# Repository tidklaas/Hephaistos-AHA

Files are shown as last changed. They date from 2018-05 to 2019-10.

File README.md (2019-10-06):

# Hephaistos-AHA
Control your heater from your FritzBox, if you dare...

This project emulates a room thermostat for a central heating unit.
It monitors a set of AVM FritzDect 301 (intelligent radiator valves)
and signals the heater to turn on or off via a simple relay circuit.

Since we are dealing with mains voltage and probably gas-powered
heating systems, you should not even think about using this contraption
unless your are a licensed electrician and/or certified HVAC technician.

Seriously, don't.

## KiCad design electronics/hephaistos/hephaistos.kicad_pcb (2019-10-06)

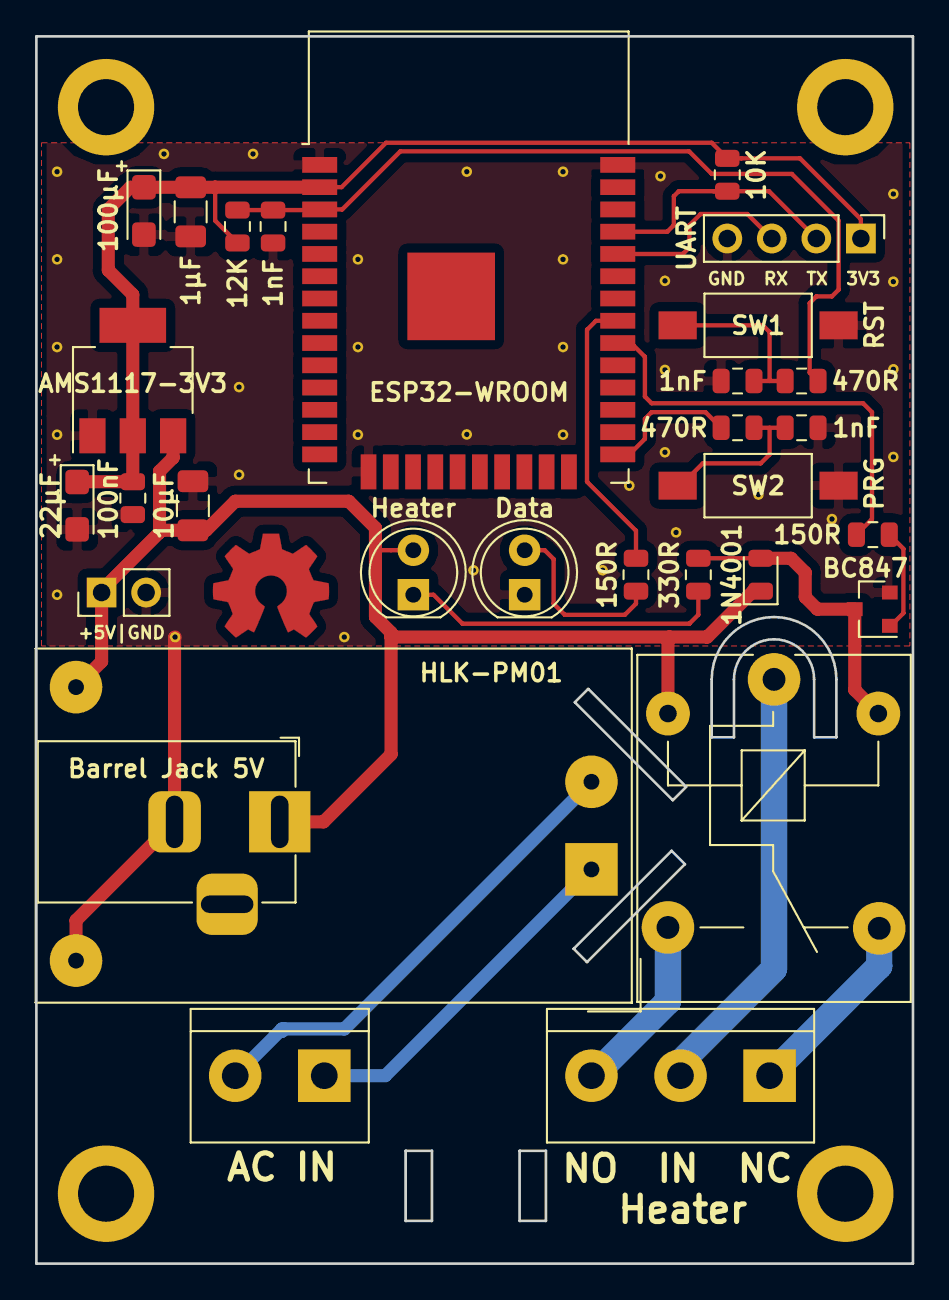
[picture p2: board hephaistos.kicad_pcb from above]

Board: 2 copper layers, 50.0 x 70.0 mm, 30 parts (0 on the bottom side), 20 nets.

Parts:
C1: 100µF; CP_EIA-3216-12_Kemet-S
C2: 1µF; C_1206_3216Metric
C3, C4, C5: 1nF; C_0805_2012Metric
C6: 10µF; C_1206_3216Metric
C7: 22µF; CP_EIA-3216-12_Kemet-S
C8: 100nF; C_0805_2012Metric
D1: Heater; LED_D5.0mm
D2: Data; LED_D5.0mm
D3: 1N4001; D_0805_2012Metric
J1: UART; PinHeader_1x04_P2.54mm_Vertical
J2: Heater; TerminalBlock_bornier-3_P5.08mm
J3: AC IN; TerminalBlock_bornier-2_P5.08mm
J4: Barrel Jack 5V; BarrelJack_Horizontal
J5: +5V Pin Header; PinHeader_1x02_P2.54mm_Vertical
K1: SANYOU_SRD_Form_C; Relay_SPDT_SANYOU_SRD_Series_Form_C
Q1: BC847; SOT-23
R1: 12K; R_0805_2012Metric
R2, R3: 470R; R_0805_2012Metric
R4: 330R; R_0805_2012Metric
R5, R7: 150R; R_0805_2012Metric
R6: 10K; R_0805_2012Metric
SW1: EN; SW_SPST_FSMSM
SW2: BOOT; SW_SPST_FSMSM
U1: ESP32-WROOM; ESP32-WROOM-32
U2: AMS1117-3V3; SOT-223-3_TabPin2
U3: HLK-PM01; Converter_ACDC_Hi-Link_HLK-PMXX_THT

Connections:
+3V3: C1.1, C2.1, C7.1, C8.1, J1.1, R1.1, R6.2, U1.2, U2.2
+5V: C6.1, D1.2, D3.1, J4.1, J5.1, K1.2, U2.3, U3.4
/IO0: R3.1, U1.25
/IO18: R5.2, U1.30
/IO19: R7.2, U1.31
/REL_IN: J2.2, K1.1
/REL_NC: J2.1, K1.4
/REL_NO: J2.3, K1.3
/RX0: J1.3, U1.34
/TX0: J1.2, R6.1, U1.35
GND: C1.2, C2.2, C3.2, C4.2, C5.2, C6.2, C7.2, C8.2, D2.1, J1.4, J4.2, J5.2, Q1.2, SW1.1, SW2.1, U1.1, U1.15, U1.38, U2.1, U3.3
unnamed: C3.1, R1.2, R2.1, U1.3
unnamed: C4.1, R2.2, SW1.2
unnamed: C5.1, R3.2, SW2.2
unnamed: D1.1, R4.2
unnamed: D2.2, R7.1
unnamed: D3.2, K1.5, Q1.3, R4.1
unnamed: J3.1, U3.1
unnamed: J3.2, U3.2
unnamed: Q1.1, R5.1

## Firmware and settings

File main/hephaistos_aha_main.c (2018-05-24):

/*
 * main.c
 *
 *  Created on: 04.11.2017
 *      Author: tido
 */

#include <string.h>
#include <stdlib.h>
#include <unistd.h>
#include <stdbool.h>
#include <sys/socket.h>
#include <netdb.h>
#include <netinet/in.h>
#include <arpa/inet.h>
#include <errno.h>
#include <expat.h>
#include <expat-dom.h>
#include <list.h>
#if !defined(ESP_PLATFORM)
#include <bsd/bsd.h>
#endif

#include <sdkconfig.h>

#if defined(ESP_PLATFORM)
#include "freertos/FreeRTOS.h"
#include "freertos/task.h"
#include "freertos/event_groups.h"
#include "esp_wifi.h"
#include "esp_event_loop.h"
#include "esp_log.h"
#include "esp_system.h"
#include "esp_task_wdt.h"
#include "nvs_flash.h"
#include "driver/gpio.h"

#include "lwip/err.h"
#include "lwip/sockets.h"
#include "lwip/sys.h"
#include "lwip/netdb.h"
#include "lwip/dns.h"

#include "apps/sntp/sntp.h"
#endif // defined(ESP_PLATFORM)

#include "mbedtls/platform.h"
#include "mbedtls/net_sockets.h"
#if defined(ESP_PLATFORM)
#include "mbedtls/esp_debug.h"
#endif // defined(ESP_PLATFORM)
#include "mbedtls/ssl.h"
#include "mbedtls/entropy.h"
#include "mbedtls/ctr_drbg.h"
#include "mbedtls/error.h"
#include "mbedtls/certs.h"
#include "mbedtls/md5.h"

/* The examples use simple WiFi configuration that you can set via
 'make menuconfig'.

 If you'd rather not, just change the below entries to strings with
 the config you want - ie #define EXAMPLE_WIFI_SSID "mywifissid"
 */
#define WIFI_SSID       CONFIG_WIFI_SSID
#define WIFI_PASS       CONFIG_WIFI_PASSWORD
#define FBOX_USER       CONFIG_FBOX_USER
#define FBOX_PASS       CONFIG_FBOX_PASSWORD
#define FBOX_ADDR       CONFIG_FBOX_ADDR
#define FBOX_PORT       CONFIG_FBOX_PORT
#define TIMEZONE        CONFIG_TIMEZONE
#define GPIO_HEAT       CONFIG_GPIO_HEAT
#define GPIO_LED        CONFIG_GPIO_LED

#define TWDT_TIMEOUT_S          300
#define TASK_RESET_PERIOD_S     5

#if defined(ESP_PLATFORM)
/* FreeRTOS event group to signal when we are connected & ready to make a request */
static EventGroupHandle_t wifi_event_group;

/* The event group allows multiple bits for each event,
 * but we only care about one event - are we connected
 * to the AP with an IP? */
const int CONNECTED_BIT = BIT0;
#else
#define ESP_LOGE(tag, format, ... )  printf("[%s]" format "\n", tag, ##__VA_ARGS__)
#define ESP_LOGI(tag, format, ... )  printf("[%s]" format "\n", tag, ##__VA_ARGS__)
#define ESP_LOGW(tag, format, ... )  printf("[%s]" format "\n", tag, ##__VA_ARGS__)
#define ESP_LOGD(tag, format, ... )  printf("[%s]" format "\n", tag, ##__VA_ARGS__)
#endif // defined(ESP_PLATFORM)

#define ARRAY_SIZE(x)   (sizeof(x) / sizeof(*(x)))
static void debug_led(unsigned int led, int on_off);

static const char *TAG = "hephaistos";

static const char *HTTP_REQ = 
        "GET %s HTTP/1.0\r\n"
        "HOST: 192.168.178.1\r\n"
        "CONNECTION: keep-alive\r\n"
        "USER-AGENT: AVM UPnP/1.0 Client 1.0\r\n"
        "\r\n";

static const char *SID_CHECK = "/login_sid.lua?sid=%s";
static const char *SID_GET = "/login_sid.lua?username=%s&response=%s-%s";
static const char *HKR_REQ = "/webservices/homeautoswitch.lua?switchcmd=getdevicelistinfos&sid=%s";

#define HTTP_REQ_SIZE   1024

enum aha_heat_mode {
    aha_heat_off = 0,
    aha_heat_keep,
    aha_heat_on
};

struct aha_state
{
#if defined(ESP_PLATFORM)
    SemaphoreHandle_t sema;
    TimerHandle_t hyst_timer;
#endif
    struct aha_list_head dev_head; // list of all devices
    struct aha_list_head grp_head; // list of all groups
};

static struct aha_state state;

#define MAX_ENTRY_LEN       128
#define MAX_GROUP_MEMBERS   16

#define HEAT_FORCE_ON   0xFE
#define HEAT_FORCE_OFF  0xFD

enum aha_entry_type
{
    aha_type_invalid = 0,
    aha_type_device,
    aha_type_group,
};

enum aha_lock_mode
{
    aha_lock_unknown = 0,
    aha_lock_on,
    aha_lock_off,
};

enum aha_switch_mode
{
    aha_switch_unknown = 0,
    aha_switch_auto,
    aha_switch_manual,
};

enum aha_switch_state
{
    aha_swstate_unknown = 0,
    aha_swstate_on,
    aha_swstate_off,
};

enum aha_alarm_mode
{
    aha_alarm_unknown = 0,
    aha_alarm_off,
    aha_alarm_on,
};

struct aha_hkr
{
    bool present;
    unsigned long set_temp;
    unsigned long act_temp;
    unsigned long comfort_temp;
    unsigned long eco_temp;
    unsigned long next_temp;
    unsigned long next_change;
    unsigned long batt_low;
    enum aha_lock_mode lock;
    enum aha_lock_mode device_lock;
    unsigned long error;
};

struct aha_switch
{
    bool present;
    enum aha_switch_state state;
    enum aha_switch_mode mode;
    enum aha_lock_mode lock;
    enum aha_lock_mode device_lock;
};

struct aha_power
{
    bool present;
    unsigned long power;
    unsigned long energy;
};

struct aha_thermo
{
    bool present;
    long temp_c;
    long offset;
};

struct aha_alarm
{
    bool present;
    enum aha_alarm_mode mode;
};

struct aha_group
{
    bool present;
    unsigned long master_dev;
    unsigned long members[MAX_GROUP_MEMBERS];
    unsigned int member_cnt;
};

struct aha_device
{
    struct aha_list_head dev_list;
    struct aha_list_head grp_list;
    struct aha_list_head member_list;
    enum aha_entry_type type;
    char name[MAX_ENTRY_LEN];
    char identifier[MAX_ENTRY_LEN];
    char fw_version[MAX_ENTRY_LEN];
    char manufacturer[MAX_ENTRY_LEN];
    char product_name[MAX_ENTRY_LEN];
    unsigned long functions;
    unsigned long id;
    unsigned long present;
    struct aha_device *group;
    struct aha_group grp;
    struct aha_switch swi;
    struct aha_power pwr;
    struct aha_thermo temp;
    struct aha_alarm alarm;
    struct aha_hkr hkr;
};

static int initialise_state(void)
{
    int result;

    result = 0;
    memset(&state, 0x0, sizeof(state));

    AHA_INIT_LIST_HEAD(&state.dev_head);
    AHA_INIT_LIST_HEAD(&state.grp_head);

#if defined(ESP_PLATFORM)
    state.sema = xSemaphoreCreateBinary();
    if(state.sema == NULL){
        ESP_LOGE(TAG, "Creating semaphore failed");
        result = -ENOMEM;
    }
#endif

    return result;
}

#if defined(ESP_PLATFORM)
static esp_err_t event_handler(void *ctx, system_event_t *event)
{
    switch(event->event_id) {
    case SYSTEM_EVENT_STA_START:
        esp_wifi_connect();
        break;
    case SYSTEM_EVENT_STA_GOT_IP:
        xEventGroupSetBits(wifi_event_group, CONNECTED_BIT);
        break;
    case SYSTEM_EVENT_STA_DISCONNECTED:
        /* This is a workaround as ESP32 WiFi libs don't currently
         * auto-reassociate. */
        esp_wifi_connect();
        xEventGroupClearBits(wifi_event_group, CONNECTED_BIT);
        break;
    default:
        break;
    }
    return ESP_OK;
}

static void initialise_wifi(void)
{
    tcpip_adapter_init();
    wifi_event_group = xEventGroupCreate();

    ESP_ERROR_CHECK(esp_event_loop_init(event_handler, NULL));

    wifi_init_config_t cfg = WIFI_INIT_CONFIG_DEFAULT();

    ESP_ERROR_CHECK(esp_wifi_init(&cfg));
    ESP_ERROR_CHECK(esp_wifi_set_storage(WIFI_STORAGE_RAM));

    wifi_config_t wifi_config = {
        .sta = {
            .ssid = WIFI_SSID,
            .password =  WIFI_PASS,
        },
    };

    ESP_LOGI(TAG, "Setting WiFi configuration SSID %s...", wifi_config.sta.ssid);

    ESP_ERROR_CHECK(esp_wifi_set_mode(WIFI_MODE_STA));
    ESP_ERROR_CHECK(esp_wifi_set_config(ESP_IF_WIFI_STA, &wifi_config));
    ESP_ERROR_CHECK(esp_wifi_start());
}
#endif // defined(ESP_PLATFORM)

struct auth_data
{
    char user[128];
    char pass[128];
    char realm[128];
    char nonce[128];
    char auth[128];
    char sid[128];
};

int gen_tr064_auth(struct auth_data *data)
{
    mbedtls_md5_context ctx;
    unsigned char md5sum[16];
    unsigned char md5str[33];
    unsigned int i;

    memset(data->auth, 0x0, sizeof(data->auth));

    mbedtls_md5_init(&ctx);
    mbedtls_md5_starts(&ctx);
    mbedtls_md5_update(&ctx, (unsigned char *) data->user, strlen(data->user));
    mbedtls_md5_update(&ctx, (unsigned char *) ":", 1);
    mbedtls_md5_update(&ctx, (unsigned char *) data->realm, strlen(data->realm));
    mbedtls_md5_update(&ctx, (unsigned char *) ":", 1);
    mbedtls_md5_update(&ctx, (unsigned char *) data->pass, strlen(data->pass));
    mbedtls_md5_finish(&ctx, md5sum);
    mbedtls_md5_free(&ctx);

    for(i = 0; i < sizeof(md5sum); ++i){
        sprintf((char *) &(md5str[2 * i]), "%02x", md5sum[i]);
    }

    mbedtls_md5_init(&ctx);
    mbedtls_md5_starts(&ctx);
    mbedtls_md5_update(&ctx, md5str, 32);
    mbedtls_md5_update(&ctx, (unsigned char *) ":", 1);
    mbedtls_md5_update(&ctx, (unsigned char *) data->nonce,
            strlen(data->nonce));
    mbedtls_md5_finish(&ctx, md5sum);
    mbedtls_md5_free(&ctx);

    memset(data->auth, 0x0, sizeof(data->auth));
    for(i = 0; i < sizeof(md5sum); ++i){
        sprintf(&(data->auth[2 * i]), "%02x", md5sum[i]);
    }

    return 0;
}

int gen_sid_auth(struct auth_data *data)
{
    mbedtls_md5_context ctx;
    unsigned char md5sum[16];
    unsigned char buf[256];
    unsigned int i, curr;

    memset(data->auth, 0x0, sizeof(data->auth));

    curr = 0;
    memset(buf, 0x0, sizeof(buf));
    for(i = 0;i < strlen(data->nonce);++i){
        buf[curr] = data->nonce[i];
        curr += 2;
    }

    buf[curr] = '-';
    curr += 2;

    for(i = 0; i < strlen(data->pass); ++i){
        buf[curr] = data->pass[i];
        curr += 2;
    }

    mbedtls_md5_init(&ctx);
    mbedtls_md5_starts(&ctx);
    mbedtls_md5_update(&ctx, (unsigned char *) buf, curr);
    mbedtls_md5_finish(&ctx, md5sum);
    mbedtls_md5_free(&ctx);

    memset(data->auth, 0x0, sizeof(data->auth));
    for(i = 0; i < sizeof(md5sum); ++i){
        sprintf(&(data->auth[2 * i]), "%02x", md5sum[i]);
    }

    return 0;
}

static int do_http_req(char *host, char *service, dom_t **dom, const char *req)
{
    char buf[64];
    char *reply;
    size_t written, len;
    void *dom_parser;
    int body, result, sock;
    struct addrinfo hints;
    struct addrinfo *info;
    struct timeval receiving_timeout;

    sock = -1;
    info = NULL;
    memset(&hints, 0x0, sizeof(hints));
    hints.ai_family = AF_INET;
    hints.ai_socktype = SOCK_STREAM;

    result = getaddrinfo(host, service, &hints, &info);

    if(result != 0 || info == NULL){
        ESP_LOGE(TAG, "DNS lookup failed err=%d %s info=%p", result, strerror(errno), info);
        goto err_out;
    }

    sock = socket(info->ai_family, info->ai_socktype, 0);
    if(sock < 0){
        ESP_LOGE(TAG, "... Failed to allocate socket.");
        result = sock;
        goto err_out;
    }

    result = connect(sock, info->ai_addr, info->ai_addrlen);
    if(result != 0){
        ESP_LOGE(TAG, "... socket connect failed result=%d", result);
        goto err_out;
    }

    written = 0;
    len = strlen(req);

    while(len > 0){
        result = write(sock, &(req[written]), len);
        if(result < 0){
            ESP_LOGE(TAG, "... socket send failed");
            goto err_out;
        }
        written += result;
        len -= result;
    }

    receiving_timeout.tv_sec = 5;
    receiving_timeout.tv_usec = 0;
    result = setsockopt(sock, SOL_SOCKET, SO_RCVTIMEO, &receiving_timeout,
            sizeof(receiving_timeout));
    if(result < 0){
        ESP_LOGE(TAG, "... failed to set socket receiving timeout");
        goto err_out;
    }

    body = 0;
    memset(buf, 0x42, 3);
    dom_parser = NULL;

    do{
        len = sizeof(buf) - 4;
        bzero(&(buf[3]), sizeof(buf) - 3);
        result = read(sock, (unsigned char *) &(buf[3]), len);
        if(result < 0){
            ESP_LOGE(TAG, "... failed to set socket receiving timeout");
            goto err_out;
        }

        /* connection closed? */
        if(result == 0){
            break;
        }

        len = result;

        if(body == 0){
            reply = strstr(buf, "\r\n\r\n");
            if(reply == NULL){
                memmove(buf, &(buf[len]), 3);
                continue;
            }
            reply += strlen("\r\n\r\n");
            len -= (reply - &(buf[3]));
            body = 1;
        }else{
            reply = &buf[3];
        }

        result = dom_parse_chunked_data(&dom_parser, dom, reply, len, 0);
    }while(1);

    result = dom_parse_chunked_data(&dom_parser, dom, NULL, 0, 1);

err_out:
    if(info != NULL){
        freeaddrinfo(info);
    }

    if(sock >= 0){
        close(sock);
    }

    if(result != 0 && *dom != NULL){
        dom_free(*dom);
        *dom = NULL;
    }

    return result;
}

static int parse_attr_ul(dom_t *dom, const char *name, unsigned long *dst)
{
    int result;
    const char *val;

    result = 0;
    val = dom_find_attr(dom->attr, name);
    if(val == NULL){
        result = -ENOENT;
        goto err_out;
    }

    errno = 0;
    *dst = strtoul(val, NULL, 10);
    result = errno;

err_out:
    return result;
}

static int __attribute__((unused)) parse_attr_long(dom_t *dom, const char *name, long *dst)
{
    int result;
    const char *val;

    result = 0;
    val = dom_find_attr(dom->attr, name);
    if(val == NULL){
        result = -ENOENT;
        goto err_out;
    }

    errno = 0;
    *dst = strtol(val, NULL, 10);
    result = errno;

err_out:
    return result;
}

static int parse_data_ul(dom_t *dom, const char *name, unsigned long *dst)
{
    int result;
    dom_t *node;
    char buf[32];

    result = 0;
    node = dom_find_node(dom, name);
    if(node == NULL){
        result = -ENOENT;
        goto err_out;
    }

    if(node->data_len >= (sizeof(buf) - 1)){
        result = -EINVAL;
        goto err_out;
    }

    memcpy(buf, node->data, node->data_len);
    buf[node->data_len] = '\0';

    errno = 0;
    *dst = strtoul(buf, NULL, 10);
    result = errno;

err_out:
    return result;
}

static int parse_data_long(dom_t *dom, const char *name, long *dst)
{
    int result;
    dom_t *node;
    char buf[32];

    result = 0;
    node = dom_find_node(dom, name);
    if(node == NULL){
        result = -ENOENT;
        goto err_out;
    }

    if(node->data_len >= (sizeof(buf) - 1)){
        result = -ENOSPC;
        goto err_out;
    }

    memcpy(buf, node->data, node->data_len);
    buf[node->data_len] = '\0';

    errno = 0;
    *dst = strtol(buf, NULL, 10);
    result = errno;

err_out:
    return result;
}

static int copy_attr_str(dom_t *dom, const char *name, char *dst, size_t len)
{
    const char *attr;
    size_t written;
    int result;

    result = 0;
    attr = dom_find_attr(dom->attr, name);
    if(attr == NULL){
        result = -ENOENT;
        goto err_out;
    }

    written = strlcpy(dst, attr, len);
    if(written >= len){
        result = -ENOSPC;
    }

err_out:
    return result;
}

static int copy_data_str(dom_t *dom, const char *name, char *dst, size_t len)
{
    dom_t *node;
    int result;

    result = 0;
    node = dom_find_node(dom, name);
    if(node == NULL){
        result = -ENOENT;
        goto err_out;
    }

    if(node->data_len >= len){
        result = -ENOSPC;
        goto err_out;
    }

    memcpy(dst, node->data, node->data_len);
    dst[node->data_len] = '\0';

err_out:
    return result;
}

static int parse_lock_state(dom_t *dom, const char *name, enum aha_lock_mode *state)
{
    unsigned long tmp;
    int result;

    result = parse_data_ul(dom, name, &tmp);
    if(result == 0){
        switch(tmp){
        case 0:
            *state = aha_lock_off;
            break;
        case 1:
            *state = aha_lock_on;
            break;
        default:
            result = -EINVAL;
            goto err_out;
        }
    }

err_out:
    return result;
}

static int parse_switch_state(dom_t *dom, const char *name, enum aha_switch_state *state)
{
    unsigned long tmp;
    int result;

    result = parse_data_ul(dom, name, &tmp);
    if(result == 0){
        switch(tmp){
        case 0:
            *state = aha_swstate_off;
            break;
        case 1:
            *state = aha_swstate_on;
            break;
        default:
            result = -EINVAL;
            goto err_out;
        }
    }

err_out:
    return result;
}

static int compare_data_str(dom_t *dom, const char *name, const char *val)
{
    dom_t *node;
    int result;

    result = 0;
    node = dom_find_node(dom, name);
    if(node == NULL){
        result = -ENOENT;
        goto err_out;
    }

    if(strncasecmp(val, node->data, node->data_len) != 0){
        result = 1;
    }

err_out:
    return result;
}

static int parse_switch_mode(dom_t *dom, const char *name, enum aha_switch_mode *mode)
{
    int result;

    result = compare_data_str(dom, name, "auto");
    if(result < 0){
        result = -EINVAL;
        goto err_out;
    } else if(result == 0){
        *mode = aha_switch_auto;
        goto err_out;
    }

    result = compare_data_str(dom, name, "manuell");
    if(result < 0){
        result = -EINVAL;
        goto err_out;
    } else if(result == 0){
        *mode = aha_switch_manual;
        goto err_out;
    }

    result = -ENOENT;

err_out:
    return result;
}

static int parse_group_entry(dom_t *dom, struct aha_device *entry)
{
    dom_t *node;
    char buf[MAX_ENTRY_LEN];
    char *tok, *saveptr;
    unsigned long val;
    int result;

    result = 0;
    node = dom_find_node(dom, "groupinfo");
    if(node == NULL){
        goto err_out;
    }

    node = node->child;

    result = parse_data_ul(node, "masterdeviceid", &(entry->grp.master_dev));
    if(result != 0 && result != -ENOENT){
        ESP_LOGE(TAG, "Parsing masterdeviceid failed for entry %s", entry->name);
        goto err_out;
    }
    result = 0;

    result = copy_data_str(node, "members", buf, sizeof(buf));
    if(result != 0){
        ESP_LOGE(TAG, "Copying member string failed for entry %s", entry->name);
        result = -EINVAL;
        goto err_out;
    }

    tok = strtok_r(buf, ",", &saveptr);
    while(tok != NULL && entry->grp.member_cnt < ARRAY_SIZE(entry->grp.members)){
        errno = 0;
        val = strtoul(tok, NULL, 10);
        if(errno != 0){
            ESP_LOGE(TAG, "Error parsing group members for entry %s", entry->name);
            result = errno;
            goto err_out;
        }

        entry->grp.members[entry->grp.member_cnt] = val;
        ++entry->grp.member_cnt;
        tok = strtok_r(NULL, ",", &saveptr);
    }

    entry->grp.present = true;

err_out:
    return result;
}

static int parse_hkr_entry(dom_t *dom, struct aha_device *entry)
{
    dom_t *node;
    int result;

    result = 0;
    node = dom_find_node(dom, "hkr");
    if(node == NULL){
        goto err_out;
    }

    node = node->child;

    result = parse_data_ul(node, "tist", &(entry->hkr.act_temp));
    if(result != 0){
        ESP_LOGE(TAG, "Error parsing actual temperature for entry %s", entry->name);
        goto err_out;
    }

    result = parse_data_ul(node, "tsoll", &(entry->hkr.set_temp));
    if(result != 0){
        ESP_LOGE(TAG, "Error parsing set temperature for entry %s", entry->name);
        goto err_out;
    }

    result = parse_data_ul(node, "komfort", &(entry->hkr.comfort_temp));
    if(result != 0){
        ESP_LOGE(TAG, "Error parsing comfort temperature for entry %s", entry->name);
        goto err_out;
    }

    result = parse_data_ul(node, "absenk", &(entry->hkr.eco_temp));
    if(result != 0){
        ESP_LOGE(TAG, "Error parsing eco temperature for entry %s", entry->name);
        goto err_out;
    }

    result = parse_data_ul(node, "errorcode", &(entry->hkr.error));
    if(result != 0){
        ESP_LOGE(TAG, "Error parsing error code for entry %s", entry->name);
        goto err_out;
    }

    result = parse_data_ul(node, "batterylow", &(entry->hkr.batt_low));
    if(result != 0){
        ESP_LOGE(TAG, "Error parsing battery status for entry %s", entry->name);
        goto err_out;
    }

    result = parse_data_ul(node, "endperiod", &(entry->hkr.next_change));
    if(result != 0){
        ESP_LOGE(TAG, "Error parsing next change time for entry %s", entry->name);
        goto err_out;
    }

    result = parse_data_ul(node, "tchange", &(entry->hkr.next_temp));
    if(result != 0){
        ESP_LOGE(TAG, "Error parsing next change temperature for entry %s", entry->name);
        goto err_out;
    }

    result = parse_lock_state(node, "lock", &(entry->hkr.lock));
    if(result != 0){
        ESP_LOGE(TAG, "Error parsing hkr lock state for entry %s", entry->name);
        goto err_out;
    }

    result = parse_lock_state(node, "devicelock", &(entry->hkr.device_lock));
    if(result != 0){
        ESP_LOGE(TAG, "Error parsing hkr device lock state for entry %s", entry->name);
        goto err_out;
    }

    entry->hkr.present = true;

err_out:
    return result;
}

static int parse_swi_entry(dom_t *dom, struct aha_device *entry)
{
    dom_t *node;
    int result;

    result = 0;
    node = dom_find_node(dom, "switch");
    if(node == NULL){
        goto err_out;
    }

    node = node->child;

    result = parse_switch_state(dom, "state", &(entry->swi.state));
    if(result != 0){
        ESP_LOGE(TAG, "Error parsing switch state for entry %s", entry->name);
        goto err_out;

    }

    result = parse_switch_mode(dom, "mode", &(entry->swi.mode));
    if(result != 0){
        ESP_LOGE(TAG, "Error parsing switch state for entry %s", entry->name);
        goto err_out;

    }

    result = parse_lock_state(node, "lock", &(entry->swi.lock));
    if(result != 0){
        ESP_LOGE(TAG, "Error parsing switch lock state for entry %s", entry->name);
        goto err_out;
    }

    result = parse_lock_state(node, "devicelock", &(entry->swi.device_lock));
    if(result != 0){
        ESP_LOGE(TAG, "Error parsing switch device lock state for entry %s", entry->name);
        goto err_out;
    }

    entry->swi.present = true;

err_out:
    return result;
}
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
int main(int argc, char **argv)
{
    get_time();
    initialise_state();
    hephaistos_task(NULL);
    return 0;
}
#endif

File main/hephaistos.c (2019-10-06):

/*
 * This file is part of the Hephaistos-AHA project.
 * Copyright (C) 2018-2019 Tido Klaassen <tido_hephaistos@4gh.eu>
 *
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
 * You should have received a copy of the GNU General Public License
 * along with this program; if not, write to the Free Software
 * Foundation, Inc., 51 Franklin Street, Fifth Floor, Boston,
 * MA  02110-1301, USA.
 */

#include <string.h>
#include <stdlib.h>
#include <unistd.h>
#include <stdbool.h>
#include <sys/socket.h>
#include <netdb.h>
#include <netinet/in.h>
#include <arpa/inet.h>
#include <errno.h>

#include <sdkconfig.h>

#include <hephaistos.h>
#include <avm_aha.h>

#include <freertos/FreeRTOS.h>
#include <freertos/task.h>
#include <freertos/event_groups.h>
#include <esp_wifi.h>
#include <esp_wps.h>
#include <esp_event.h>
#include <esp_log.h>
#include <esp_system.h>
#include <esp_task_wdt.h>
#include <nvs_flash.h>
#include <driver/gpio.h>
#include <driver/ledc.h>
#include <esp_intr_alloc.h>
#include <esp32/rom/rtc.h>
#include <esp_ota_ops.h>
#include <esp_image_format.h>
#include <esp_sntp.h>

#include <lwip/err.h>
#include <lwip/sockets.h>
#include <lwip/sys.h>
#include <lwip/netdb.h>
#include <lwip/dns.h>

#include <wifi_manager.h>
#include <libesphttpd/cgiwifi.h>
#include <http_srv.h>

#define TIMEZONE        CONFIG_TIMEZONE
#define GPIO_HEAT       CONFIG_GPIO_HEAT
#define GPIO_LED        CONFIG_GPIO_LED
#define GPIO_FW_RESET   CONFIG_GPIO_FW_RESET

#define TWDT_TIMEOUT_S          300
#define TASK_RESET_PERIOD_S     5
#define FW_RESET_TIME           10

static struct heph_cfg heph_cfg;
static char sntp_srv[64];

static SemaphoreHandle_t cfg_lock = NULL;

static EventGroupHandle_t heph_event_group;
static TimerHandle_t heph_timer = NULL;
static TimerHandle_t fwrst_timer = NULL;

#define HEPH_MAGIC  0x48455048  /* "HEPH" */

__NOINIT_ATTR static volatile struct _restart_marker {
    uint32_t magic;
    uint32_t count;
} restart_marker;

static const char *TAG = "HEPH";

static const int BIT_TRIGGER       = BIT0;
static const int BIT_RELOAD_CFG    = BIT1;
static const int BIT_NTP_SYNC      = BIT2;
static const int BIT_AHA_CFG       = BIT3;
static const int BIT_AHA_RUN       = BIT4;
static const int BIT_FW_RESET      = BIT5;

static void update_sntp_cb(struct timeval *tv)
{
    char buff[64];
    struct tm tm;

    memset(&tm, 0x0, sizeof(tm));
    localtime_r(&(tv->tv_sec), &tm);

    if(tm.tm_year > (2016 - 1900)){
        ESP_LOGI(TAG, "[%s] Got NTP time sync: %s",
                __func__, asctime_r(&tm, buff));

        xEventGroupSetBits(heph_event_group, BIT_NTP_SYNC);
    }
}

static void update_sntp(void)
{
    bool connected, running, cfg_changed;
    struct aha_cfg aha_cfg;
    esp_err_t result;

    cfg_changed = false;
    result = aha_get_cfg(&aha_cfg, cfg_ram);
    if(result == ESP_ERR_TIMEOUT){
        /* Temporary error, return immediately. */
        goto on_exit;
    }

    if(result != ESP_OK
       || strncmp(sntp_srv, aha_cfg.fbox_addr, sizeof(aha_cfg.fbox_addr)))
    {
        cfg_changed = true;
    }

    connected = esp_wmngr_is_connected();
    running = sntp_enabled();

    if(running){
        if(!connected || cfg_changed){
            ESP_LOGI(TAG, "Stopping SNTP");
            sntp_stop();
            memset(sntp_srv, 0x0, sizeof(sntp_srv));
            xEventGroupClearBits(heph_event_group, BIT_NTP_SYNC);
            running = false;
        }
    }

    if(connected && !running){
        if(strnlen(aha_cfg.fbox_addr, sizeof(aha_cfg.fbox_addr)) == 0){
            ESP_LOGD(TAG, "[%s] fbox_addr empty", __func__);
            goto on_exit;
        }

        ESP_LOGI(TAG, "Starting SNTP");
        ESP_LOGI(TAG, "SNTP-Server: %s", aha_cfg.fbox_addr);
        strlcpy(sntp_srv, aha_cfg.fbox_addr, sizeof(sntp_srv));
        sntp_set_time_sync_notification_cb(update_sntp_cb);
        sntp_setoperatingmode(SNTP_OPMODE_POLL);
        sntp_setservername(0, sntp_srv);
        sntp_init();
    }

on_exit:
    return;
}

esp_err_t heph_set_cfg(struct heph_cfg *cfg, bool reload)
{
    esp_err_t result;
    nvs_handle handle;

    if(cfg_lock == NULL){
        return ESP_ERR_TIMEOUT;
    }

    result = nvs_open(HEPH_NVS_NAMESPC, NVS_READWRITE, &handle);
    if(result != ESP_OK){
        return result;
    }

    if(xSemaphoreTake(cfg_lock, 100 * portTICK_PERIOD_MS) != pdTRUE){
        result = ESP_ERR_TIMEOUT;
        goto on_exit;
    }

    /* Timezone is optional */
    if(strlen(cfg->tz) > 0){
        result = nvs_set_str(handle, "timezone", cfg->tz);
        if(result != ESP_OK){
            goto on_exit_unlock;
        }
    }

    result = nvs_commit(handle);
    if(result != ESP_OK){
        goto on_exit_unlock;
    }

    if(reload){
        xEventGroupSetBits(heph_event_group, (BIT_RELOAD_CFG | BIT_TRIGGER));
    }

on_exit_unlock:
    xSemaphoreGive(cfg_lock);

on_exit:
    nvs_close(handle);

    return result;
}

esp_err_t heph_get_cfg(struct heph_cfg *cfg, enum cfg_load_type from)
{
    esp_err_t result;
    size_t len;
    nvs_handle handle;

    if(from != cfg_nvs && from != cfg_ram){
        return ESP_ERR_INVALID_ARG;
    }

    if(cfg_lock == NULL){
        return ESP_ERR_TIMEOUT;
    }

    if(from == cfg_nvs){
        result = nvs_open(HEPH_NVS_NAMESPC, NVS_READONLY, &handle);
        if(result != ESP_OK){
            return result;
        }
    }

    if(xSemaphoreTake(cfg_lock, 100 * portTICK_PERIOD_MS) != pdTRUE){
        result = ESP_ERR_TIMEOUT;
        goto on_exit;
    }

    if(from == cfg_ram){
        memmove(cfg, &heph_cfg, sizeof(*cfg));
        result = ESP_OK;
        goto on_exit_unlock;
    }

    memset(cfg, 0x0, sizeof(*cfg));

    /* Try to read timezone. Fall back to default if not set */
    len = sizeof(cfg->tz);
    result = nvs_get_str(handle, "timezone", cfg->tz, &len);
    if((result != ESP_OK) || (strlen(cfg->tz) == 0)){
        strlcpy(cfg->tz, TIMEZONE, sizeof(cfg->tz));
        result = ESP_OK;
    }

on_exit_unlock:
    xSemaphoreGive(cfg_lock);

on_exit:
    if(from == cfg_nvs){
        nvs_close(handle);
    }

    return result;
}

static esp_err_t reload_cfg(void)
{
    esp_err_t result;
    struct heph_cfg cfg;

    result = heph_get_cfg(&cfg, cfg_nvs);
    if(result != ESP_OK){
        ESP_LOGE(TAG, "[%s] heph_get_cfg() failed", __func__);
        goto on_exit;
    }

    if(xSemaphoreTake(cfg_lock, 100 * portTICK_PERIOD_MS) != pdTRUE){
        result = ESP_ERR_TIMEOUT;
        goto on_exit;
    }

    memmove(&heph_cfg, &cfg, sizeof(heph_cfg));

    xSemaphoreGive(cfg_lock);

    if(strlen(heph_cfg.tz) > 0){
        ESP_LOGI(TAG, "[%s] Setting TZ to %s", __func__, heph_cfg.tz);
        setenv("TZ", heph_cfg.tz, 1);
        tzset();
    }

on_exit:
    return result;
}

static void timer_cb(TimerHandle_t timer)
{

    if(timer == fwrst_timer){
        xEventGroupSetBits(heph_event_group, BIT_FW_RESET);
    }

    xEventGroupSetBits(heph_event_group, BIT_TRIGGER);
}
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

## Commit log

2017-11-20 Initial Commit
    - base copied from standard esp-idf examples
    - add expat-dom as submodule component
    - add Kconfig for project configuration (credentials, timezone, ...)
    - add initial implementation of retrieving and parsing AHA data from F!Box
    - add control of heater via GPIO
    - add support for building stand-alone application on UN*X machines
2018-05-24 Enable Task Watchdog and Fix Device Evaluation
    Kconfig:
    - rename CTRL_GPIO to GPIO_HEAT, add GPIO_LED
    hephaistos_aha_main.c:
    - add update indication LED GPIO
    - enable task watchdog
    - ignore group temperature data for heater control
    - keep all devices on global device list instead of per group lists
    [hephaistos_aha_main.c]
2018-07-25 WIP: Setup/Config/Data via HTTP, Factory Reset
    - add rudimentary support for setting up and reconfiguring device via HTTP
    - add CGI for dumping current AHA data
    - add factory reset functionality via long button press
    - fix serious memory leak in avm_aha when socket read fails
    - remove direct GPIO manipulations from avm_aha, use functions provided
    by main hephaistos module instead.
    - change all x_get_cfg() functions so current in-memory config can be
    requested, not only the config saved in NVS.
    - some work on cleaning up wifi configuration CGIs
    - refactor commonly used data types and structs into header file heph_types.h
    - update libesphttpd
    - ...
    [hephaistos.c]
2019-05-07 WIP: Update to current libesphttpd
    - update libesphttpd submodule
    - add espfs component refactored from libesphttd
    - make necessary changes to httpd_srv.c due to refactoring
2019-09-16 avm_aha: Fix HKR Parser
    - Data fields for battery may not be present, so check for existence before
    parsing.
    - Add parsing for battery level, open window detection, summer and vacation
    modes.
2019-10-06 General Clean-Up
    avm_aha:
    - Add heater state (on/off) to aha_data.
    - Let AHA task update its config even when it is suspended. Needed to be
    able to set new AHA config when current config is bogus and system can
    not fetch NTP data.
    heph_cgi:
    - Redirect to /index.tpl by default.
    - Show some system status data on main page.
    - Add CGI for resetting WiFi Manager's configuration.
    - Also dump status, timestamp, heater state and AHA message from aha_data.
    hephaistos:
    - Use F!Box from AHA config as NTP server so no internet connectivity is
    required.
    - Allow SNTP reconfiguration after start-up.
    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
    [hephaistos.c]
2019-10-06 Add Hephaistos Hardware
    [hephaistos.kicad_pcb, hephaistos.sch]

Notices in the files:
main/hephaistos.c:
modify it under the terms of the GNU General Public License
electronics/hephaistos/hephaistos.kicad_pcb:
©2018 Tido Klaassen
